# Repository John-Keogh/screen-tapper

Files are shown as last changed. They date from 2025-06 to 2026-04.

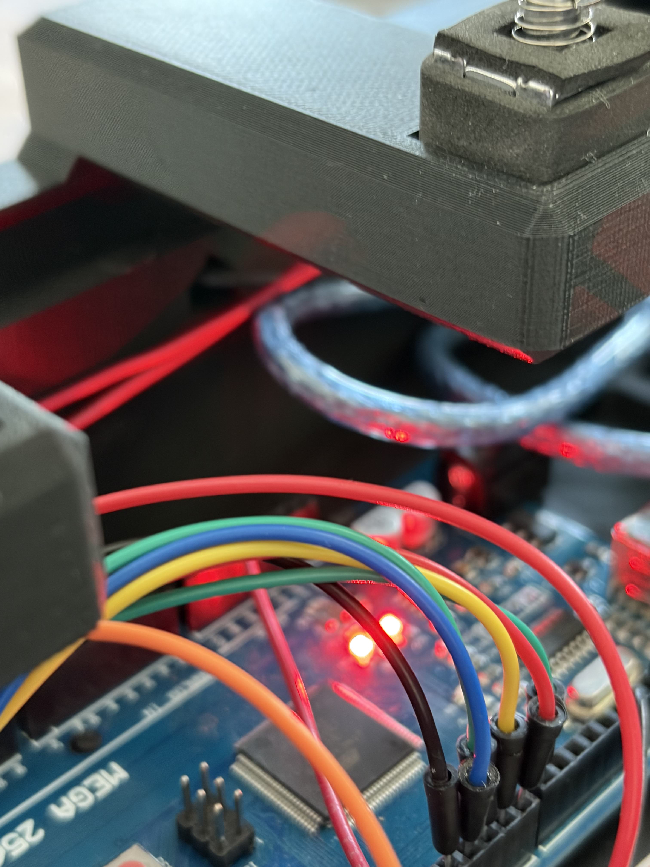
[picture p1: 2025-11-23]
images/1.2/IMG_0665.jpg

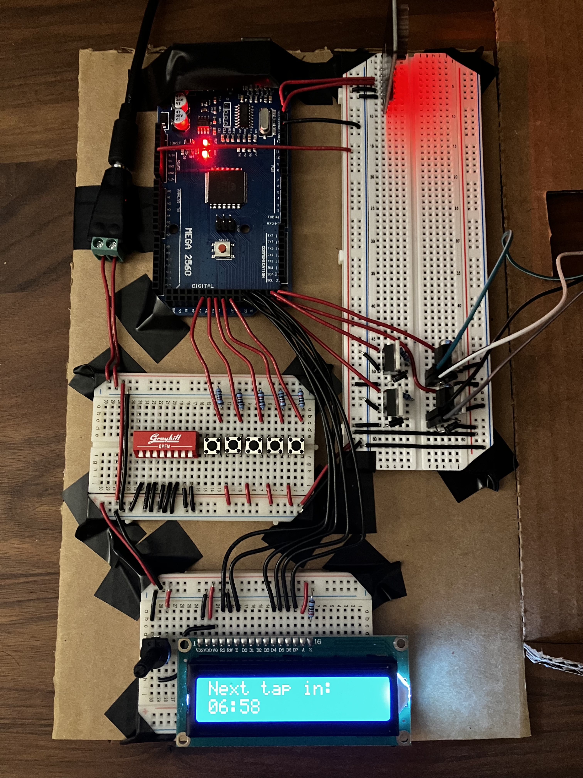
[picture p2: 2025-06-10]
images/beta/IMG_9934.jpeg

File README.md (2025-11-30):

# Screen Tapper

Updated 11/29/25 - current version is 1.2

In 2024, I got addicted to a mobile game containing a currency that can only be acquired by tapping the screen every so often. While I've been running the game 24/7 on an old device, I'm unable to claim this currency because I leave the device at home, and my schedule only allows me to collect for a few hours each day. After getting tired of being bottlenecked by this currency, I decided to try to create a device that would farm for me while I was away. The terms of service of this specific game do explicitly state that the use of external software/hardware to gain an unfair advantage can result in the abuser's account being banned. Arguably, this isn't an unfair advantage because I am not exceeding the limits of what would theoretically be possible if I were to play the game all day every day. Regardless, my goal with this device is to be as undetectable as possible, so I'll omit details about the specific game. I have accepted the fact that I could be banned for this, and I'm okay with that. Learning about electronics and continuing to broaden my engineering skills is well worth the risk, especially since I've been having so much fun with this project.

Overall, this project can be broken up into several main components: the electronic hardware, the software, and the mechanical housing.

## Electronic Hardware

The brains of this device started out on an Arduino Uno R3, but I have since upgraded to an Arduino Mega 2560 for the additional space and I/O support. The power comes from a USB wall adapter through the USB-B port. Interaction with the mobile device is carried out by two 5V solenoid valves that are controlled using one MOSFET each. A Real Time Clock (RTC) module provides time-keeping, and a rotary encoder facilitates user control. An LCD screen provides additional external information. The RTC, MOSFETs, buttons, etc. are all connected using a breadboard.

## Software

The software for the arduino is contained in a single .ino file, but a number of .h/.cpp files organize various functions, such as the LCD display, rotary encoder input, clock. etc. The RTC is used to automatically simulate a "bed time" for the device to better match the behavior of a real person. During normal sleeping hours, the device ceases operations, and at a defined wake-up time, it resumes. Fortunately, the game resource being collected is available on a mostly consistent basis. The average length of time between collections was first determined manually. That length of time (plus some small buffer) acts as the basis for the activation timer for the solenoids. Some additional random noise and occasional delays is then added to simulate the randomness of a human playing the game organically.

## Mechanical housing

The housing has been upgraded using 3d-printed components that securely hold the device and the solenoids. The housing contains internal wire channels for the solenoids to provide a cleaner aesthetic, and the entire thing has been shrunk to be as small as possible with the current overall layout and electronics.

## Future Plans

### Electronic Hardware

While I've upgraded from jumper cables to custom lines of #22 solid core wire (which made a surprisingly big improvement in overall quality of life when working with this thing), I eventually want to learn how to design a single, custom PCB to power the device. As a mechanical engineer who always avoided the electronics lab, I'm expecting this to be the most challenging part of the project. My vision is to have a single board that everything is soldered to and has sufficient customization via on-board controls (buttons/switches) that never needs to be plugged into a computer again after the software is initially installed. One nice-to-have feature I'd like to add eventually is the ability to log all actions onto an SD or micro SD card for future analysis to assess the device's performance. I'd also like to add a third solenoid for even more automated gameplay control.

### Software

Software is mostly complete, offering a variety of manual controls including tap duration, sleep/wake times, bedtime override, and device on/off override. The UI is clean enough, and at this point there are no plans for significant future changes unless I add a third solenoid.

### Mechanical Housing

The current housing is highly simplified, clean, and sturdy. I will need to update it if I add a third solenoid. Otherwise, I would still like to experiment with the idea of creating a travel version, but that would likely only come after I upgraded the electronics to a custom PCB. Otherwise, I may experiment with moving the LCD in order to make the entire device lower profile since that is currently driving the height of the device. That would likely also only come after a custom PCB implementation reduced the wires in the electronics.

TODO:
1) Add third solenoid to rear housing for alternate screen config
2) Extend front housing by ~.5 inches to allow clearance for charging cable
3) Raise tablet surface by ~.25 inches to avoid interference with control knob
4) Improve cover design to ensure clean edges/seam with front housing
5) (Optional) add supports/integration for tablet charging cable

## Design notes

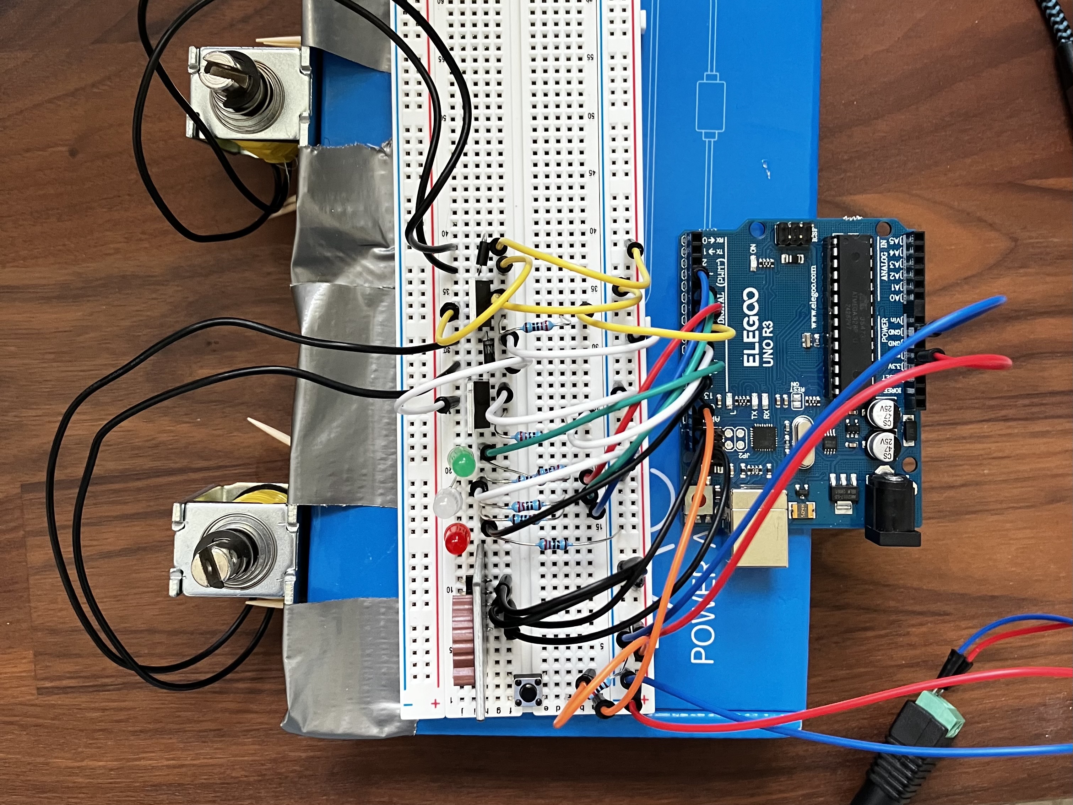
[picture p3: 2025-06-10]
images/alpha/alpha.jpeg

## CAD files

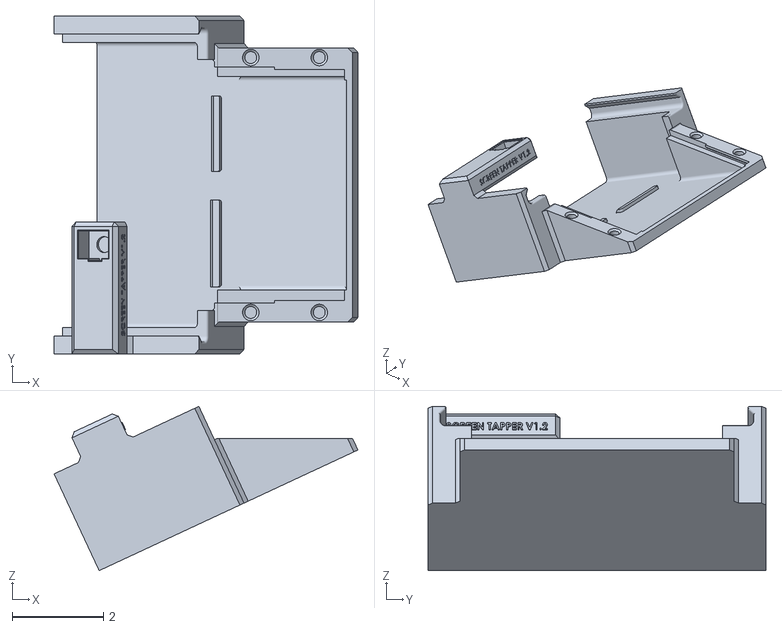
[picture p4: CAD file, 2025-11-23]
hardware/CAD/STL/frontHousing_v3.STL
6.65 x 7.40 x 3.60

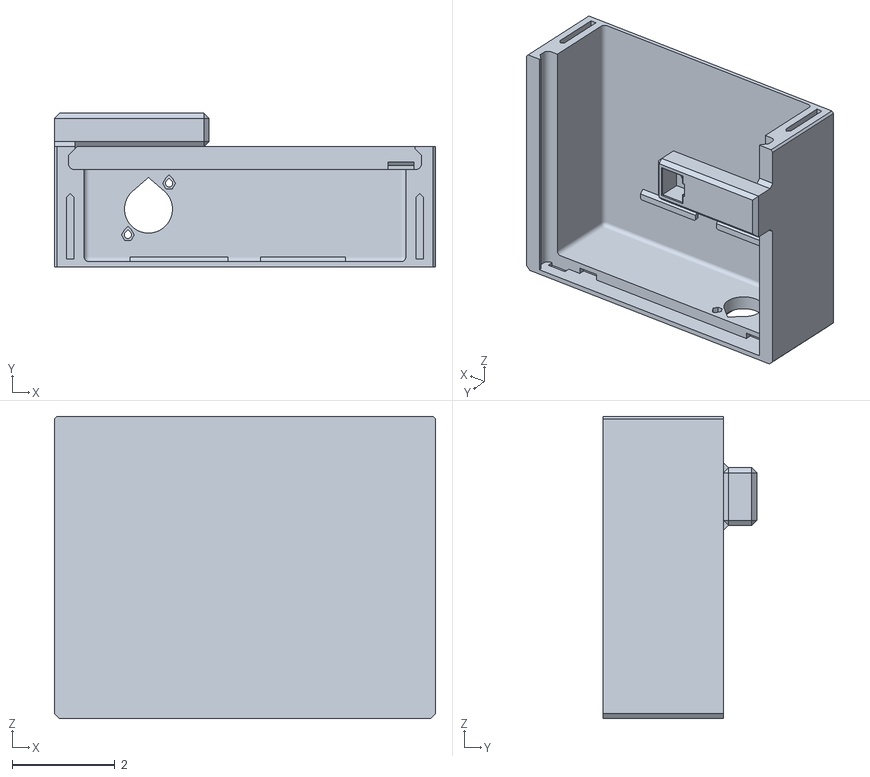
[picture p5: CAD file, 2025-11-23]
hardware/CAD/STL/housing_v4.STL
7.40 x 2.99 x 5.88

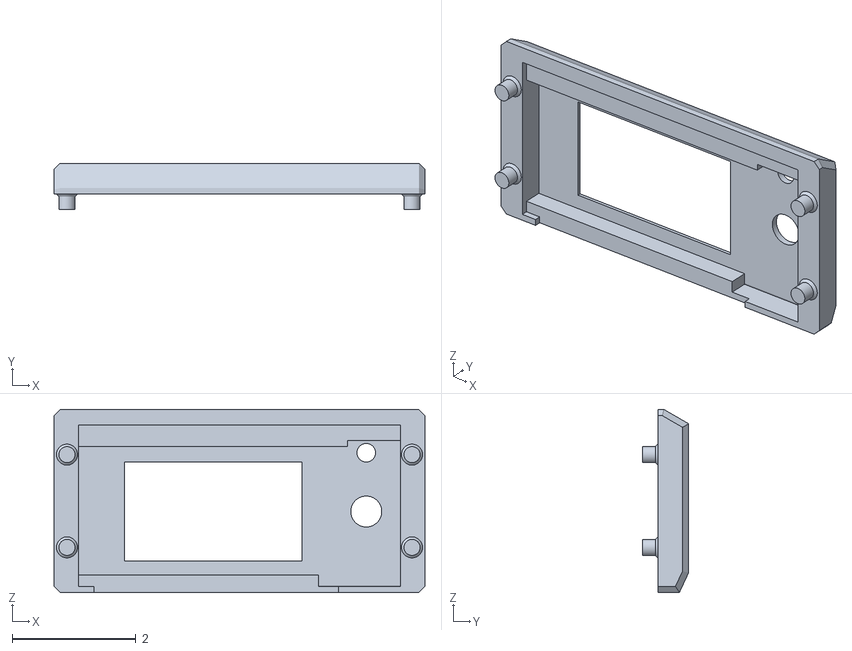
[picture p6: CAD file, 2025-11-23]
hardware/CAD/STL/LcdCover_v5.STL
6.00 x 0.75 x 2.96

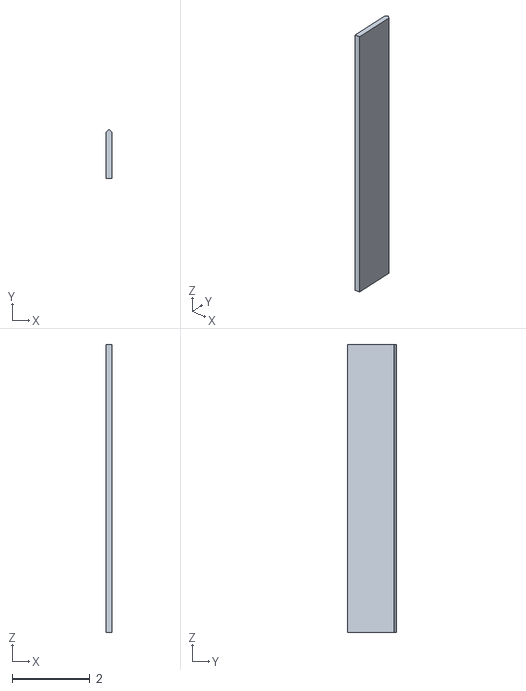
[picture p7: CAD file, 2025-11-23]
hardware/CAD/STL/spline_v2.STL
0.145 x 1.27 x 7.40

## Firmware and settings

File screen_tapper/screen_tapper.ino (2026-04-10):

#include <Wire.h>
#include <RTClib.h>
#include <EEPROM.h>
#include "config.h"
#include "clock.h"
#include "tapper.h"
#include "gem_store.h"
#include "encoder.h"
#include "button.h"
#include "menu.h"
#include "display.h"
#include "settings_store.h"

// ===========================================================================
// Application state
// ===========================================================================

// Tap settings — initialized from EEPROM in setup(), then kept in sync.
uint16_t tapDuration = 160;
uint16_t tapDuty     = 160;

// Active mode parameters (switches between kModeActual and kModeTest)
ModeParams activeMode = kModeActual;

// Sleep schedule — defaults in SleepSchedule struct, overwritten by
// settings_load() if valid EEPROM data exists.
SleepSchedule sched;

// Device flags
bool deviceEnabled   = true;
bool testModeEnabled = false;
bool overrideClock   = false;

// Tap scheduling
unsigned long nextTapTime = 0;

// ===========================================================================
// Helpers
// ===========================================================================

// Build a Settings snapshot from current runtime state for EEPROM saves.
static Settings currentSettings() {
    Settings s;
    s.sched       = sched;
    s.tapDuration = tapDuration;
    s.tapDuty     = tapDuty;
    return s;
}

// ===========================================================================
// Forward declarations
// ===========================================================================

void scheduleNextTap();
static void handleMenuAction(const MenuAction& act);
static MenuView buildMenuView(uint32_t msLeft);

// ===========================================================================
// setup()
// ===========================================================================

void setup() {
    Serial.begin(9600);
    randomSeed(analogRead(0));
    delay(1000);

    clock_begin();

    // Load persisted settings before initializing hardware that uses them.
    Settings s;
    settings_load(s);
    sched       = s.sched;
    tapDuration = s.tapDuration;
    tapDuty     = s.tapDuty;

    tapper_setDuty(tapDuty);
    tapper_begin(AD_GEMS_MOSFET_GATE_PIN, FLOAT_GEMS_MOSFET_GATE_PIN);

    encoder_begin(ENCODER_CLK, ENCODER_DT, ENCODER_SW);
    button_begin(RESET_BUTTON_PIN);
    menu_begin();
    display_begin();

    gem_store_begin();

    Serial.print(F("Lifetime gems: ")); Serial.println(gem_store_read_lifetime());
    Serial.print(F("Sleep:         ")); Serial.print(sched.sleepHour); Serial.print(':'); Serial.println(sched.sleepMinute);
    Serial.print(F("Wake:          ")); Serial.print(sched.wakeHour);  Serial.print(':'); Serial.println(sched.wakeMinute);
    Serial.print(F("Tap duration:  ")); Serial.print(tapDuration); Serial.println(F(" ms"));
    Serial.print(F("Tap duty:      ")); Serial.println(tapDuty);

    scheduleNextTap();
}

// ===========================================================================
// loop()
// ===========================================================================

void loop() {
    uint32_t now = millis();

    // --- Input: encoder ---
    // Processed before rendering so state changes appear in the same frame.
    EncoderEvents ev = encoder_poll();
    bool hadInput = (ev.delta != 0 || ev.pressed);

    MenuAction act;
    bool actionFired = menu_update(ev.delta, ev.pressed, act);
    if (actionFired) {
        handleMenuAction(act);
    }

    // --- Input: reset button ---
    // Reschedules the next tap immediately, regardless of device or sleep state.
    if (button_poll()) {
        scheduleNextTap();
        hadInput = true;
        display_markDirty();
        Serial.println(F("Reset button: next tap rescheduled"));
    }

    // --- Sleep/wake transition ---
    static bool wasAwake = false;
    bool awake = overrideClock || clock_isAwake(sched);
    if (awake && !wasAwake) scheduleNextTap();
    wasAwake = awake;

    // --- Advance tapper state machine ---
    tapper_update(now);

    // --- Fire a tap cycle when it's time ---
    if (!tapper_isActive() && deviceEnabled && awake && (int32_t)(now - nextTapTime) >= 0) {
        tapper_startCycle(
            activeMode.adGemTaps,
            activeMode.floatGemTaps,
            tapDuration,
            activeMode.pauseBetweenTapsMs,
            now
        );

        // Gem accounting: 5 gems per activation, +2 bonus every 6th activation.
        // TODO: refine once earning rates are fully characterized.
        static uint8_t activationCount = 0;
        uint32_t earned = 5;
        activationCount++;
        if (activationCount >= 6) {
            earned += 2;
            activationCount = 0;
        }
        gem_store_add_session(earned);
        scheduleNextTap();
    }

    // --- Compute msLeft ---
    // When the device is off, force to zero so the display shows 00:00.
    uint32_t msLeft = 0;
    if (deviceEnabled) {
        int32_t dt = (int32_t)(nextTapTime - now);
        if (dt > 0) msLeft = (uint32_t)dt;
    }

    // --- Render display ---
    MenuView v = buildMenuView(msLeft);

    if (hadInput || actionFired) {
        display_markDirty();
        display_renderNow(v);
    } else {
        static uint32_t lastSecondsLeft = UINT32_MAX;
        static uint32_t lastGems        = UINT32_MAX;
        uint32_t secondsLeft = msLeft / 1000;
        if (secondsLeft != lastSecondsLeft || v.lifetimeGems != lastGems) {
            display_markDirty();
            lastSecondsLeft = secondsLeft;
            lastGems        = v.lifetimeGems;
        }
        display_render(v);
    }
}

// ===========================================================================
// Tap scheduling
// ===========================================================================

void scheduleNextTap() {
    long jitter = random(-(long)activeMode.jitterRangeMs, (long)activeMode.jitterRangeMs);

    bool addBreak = !testModeEnabled && (random(12) == 0);
    unsigned long base = millis() + activeMode.baseIntervalMs;
    if (addBreak) {
        base += (unsigned long)random(3UL * 60 * 1000, 8UL * 60 * 1000);
    }

    long adjusted = (long)base + jitter;
    if (adjusted < 0) adjusted = 0;
    nextTapTime = (unsigned long)adjusted;
}

// ===========================================================================
// Menu action handler
// ===========================================================================

static void handleMenuAction(const MenuAction& act) {
    switch (act.type) {

        case MenuActionType::GoHome:
            menu_reset();
            display_markDirty();
            break;

        case MenuActionType::ToggleDeviceEnabled:
            deviceEnabled = !deviceEnabled;
            if (!deviceEnabled) {
                tapper_stop();
            } else {
                scheduleNextTap();
            }
            menu_reset();
            display_markDirty();
            break;

        case MenuActionType::ResetNextTap:
            scheduleNextTap();
            menu_reset();
            display_markDirty();
            break;

        case MenuActionType::SetTapDuration:
            if (!act.committed) {
                menu_openTapDurationEditor(tapDuration);
            } else {
                tapDuration = act.u16a;
                settings_save(currentSettings());
                menu_reset();
            }
            display_markDirty();
            break;

        case MenuActionType::SetTapDuty:
            if (!act.committed) {
                menu_openTapDutyEditor(tapDuty);
            } else {
                tapDuty = act.u16a;
                tapper_setDuty(tapDuty);
                settings_save(currentSettings());
                menu_reset();
            }
            display_markDirty();
            break;

        case MenuActionType::EnterSleepTimeEditor:
            menu_openSleepTimeEditor(sched.sleepHour, sched.sleepMinute);
            display_markDirty();
            break;

        case MenuActionType::EnterWakeTimeEditor:
            menu_openWakeTimeEditor(sched.wakeHour, sched.wakeMinute);
            display_markDirty();
            break;

        case MenuActionType::SetSleepTime:
            if (act.committed) {
                sched.sleepHour   = (uint8_t)act.u16a;
                sched.sleepMinute = (uint8_t)act.u16b;
                settings_save(currentSettings());
                menu_reset();
                display_markDirty();
            }
            break;

        case MenuActionType::SetWakeTime:
            if (act.committed) {
                sched.wakeHour   = (uint8_t)act.u16a;
                sched.wakeMinute = (uint8_t)act.u16b;
                settings_save(currentSettings());
                menu_reset();
                display_markDirty();
            }
            break;

        case MenuActionType::SetGemCount:
            if (!act.committed) {
                menu_openGemCountEditor(gem_store_total());
            } else {
                gem_store_write_lifetime(act.u32);
                menu_reset();
            }
            display_markDirty();
            break;

        case MenuActionType::ToggleTestMode:
            testModeEnabled = !testModeEnabled;
            activeMode      = testModeEnabled ? kModeTest : kModeActual;
            scheduleNextTap();
            menu_reset();
            display_markDirty();
            break;

        case MenuActionType::ToggleOverrideSleep:
            overrideClock = !overrideClock;
            menu_reset();
            display_markDirty();
            break;

        default:
            break;
    }
}

// ===========================================================================
// View construction
// ===========================================================================

static MenuView buildMenuView(uint32_t msLeft) {
    MenuHomeData hd;
    hd.lifetimeGems = gem_store_total();
    hd.msLeft       = msLeft;
    menu_setHomeData(hd);

    MenuView v;
    menu_getView(v);

    v.lifetimeGems    = gem_store_total();
    v.msLeft          = msLeft;
    v.sleepHour       = sched.sleepHour;
    v.sleepMinute     = sched.sleepMinute;
    v.wakeHour        = sched.wakeHour;
    v.wakeMinute      = sched.wakeMinute;
    v.deviceEnabled   = deviceEnabled;
    v.overrideClock   = overrideClock;
    v.tapDuration     = tapDuration;
    v.testModeEnabled = testModeEnabled;

    return v;
}

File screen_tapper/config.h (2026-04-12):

#pragma once
#include <stdint.h>

// =============================================================================
// DEBUG
// Comment out this line to strip all debug Serial output from the build.
// =============================================================================
// #define DEBUG

// =============================================================================
// PIN ASSIGNMENTS
// =============================================================================

// MOSFET gates (solenoid drivers)
constexpr int AD_GEMS_MOSFET_GATE_PIN    = 9;
constexpr int FLOAT_GEMS_MOSFET_GATE_PIN = 11;

// Rotary encoder
constexpr int ENCODER_CLK = 40;
constexpr int ENCODER_DT  = 42;
constexpr int ENCODER_SW  = 44;

// 128x64 LCD (ST7920, software SPI) — pins 4, 6, 8 only; backlight not PWM-controlled
constexpr int LCD12864_CLK = 53;
constexpr int LCD12864_DAT = 51;
constexpr int LCD12864_CS  = 49;

// Tap-timer reset button (mounted on LCD module, INPUT_PULLUP, active LOW)
constexpr int RESET_BUTTON_PIN = 31;

// =============================================================================
// TAP TIMING PARAMETERS
// =============================================================================

struct ModeParams {
    uint32_t baseIntervalMs;    // nominal time between tap cycles (ms)
    uint32_t jitterRangeMs;     // +/- random jitter added to each interval (ms)
    uint16_t pauseBetweenTapsMs;// pause between individual taps within a cycle (ms)
    uint8_t  adGemTaps;         // number of taps for the ad-gem solenoid per cycle
    uint8_t  floatGemTaps;      // number of taps for the float-gem solenoid per cycle
};

// Normal operating mode
constexpr ModeParams kModeActual = {
    670000,  // baseIntervalMs
    16000,   // jitterRangeMs
    750,     // pauseBetweenTapsMs
    5,       // adGemTaps
    17,      // floatGemTaps
};

// Faster test mode for verifying hardware behavior
constexpr ModeParams kModeTest = {
    7000,    // baseIntervalMs
    0,       // jitterRangeMs
    750,     // pauseBetweenTapsMs
    3,       // adGemTaps
    5,       // floatGemTaps
};

// =============================================================================
// SLEEP SCHEDULE
// =============================================================================

struct SleepSchedule {
    uint8_t wakeHour   = 7;
    uint8_t wakeMinute = 30;
    uint8_t sleepHour  = 23;
    uint8_t sleepMinute = 59;
};

inline uint16_t toMinutes(uint8_t h, uint8_t m) { return h * 60u + m; }

// =============================================================================
// GEM STORE
// =============================================================================

// Save lifetime gem count to EEPROM after this many session gems accumulate.
constexpr uint16_t kGemSaveThreshold = 25;

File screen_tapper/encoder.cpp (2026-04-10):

#include "encoder.h"
#include "config.h"
#include <Arduino.h>

// Debounce window for the push switch
static constexpr unsigned long SW_DEBOUNCE_MS = 30;

// Pin storage
static uint8_t s_clk = 0xFF;
static uint8_t s_dt  = 0xFF;
static uint8_t s_sw  = 0xFF;

// Rotation detection
static uint8_t s_lastClk = HIGH;

// Switch debounce state (active LOW)
static unsigned long s_swLastChangeMs = 0;
static uint8_t       s_swLastStable   = HIGH;

#ifdef DEBUG
static long s_debugCount = 0;
#endif

void encoder_begin(uint8_t clkPin, uint8_t dtPin, uint8_t swPin) {
    s_clk = clkPin;
    s_dt  = dtPin;
    s_sw  = swPin;

    pinMode(s_clk, INPUT_PULLUP);
    pinMode(s_dt,  INPUT_PULLUP);
    pinMode(s_sw,  INPUT_PULLUP);

    s_lastClk      = digitalRead(s_clk);
    s_swLastStable = digitalRead(s_sw);
    s_swLastChangeMs = millis();

#ifdef DEBUG
    s_debugCount = 0;
    Serial.println(F("[ENC] begin"));
    Serial.print(F("[ENC] pins: CLK=")); Serial.print(s_clk);
    Serial.print(F(" DT="));             Serial.print(s_dt);
    Serial.print(F(" SW="));             Serial.println(s_sw);
    Serial.print(F("[ENC] init CLK="));  Serial.print(s_lastClk);
    Serial.print(F(" DT="));             Serial.println(digitalRead(s_dt));
    Serial.println(F("[ENC] debug counter reset to 0"));
#endif
}

EncoderEvents encoder_poll() {
    EncoderEvents ev;
    unsigned long now = millis();

    // Rotation: report one step per falling edge of CLK
    uint8_t clkNow = digitalRead(s_clk);
    if (clkNow != s_lastClk && clkNow == LOW) {
        uint8_t dtNow = digitalRead(s_dt);
        int8_t step = (dtNow != clkNow) ? +1 : -1;
        // If direction feels reversed on your hardware, flip the sign:
        // step = -step;
        ev.delta += step;

#ifdef DEBUG
        s_debugCount += step;
        Serial.print(F("[ENC] STEP "));
        Serial.print((step > 0) ? F("CW ") : F("CCW "));
        Serial.print(F("clk=")); Serial.print(clkNow);
        Serial.print(F(" dt="));  Serial.print(dtNow);
        Serial.print(F("  count=")); Serial.println(s_debugCount);
#endif
    }
    s_lastClk = clkNow;

    // Press: debounced falling edge detection
    uint8_t swNow = digitalRead(s_sw);
    if (swNow != s_swLastStable && (now - s_swLastChangeMs) >= SW_DEBOUNCE_MS) {
        s_swLastChangeMs = now;
        if (swNow == LOW) {
            ev.pressed = true;
#ifdef DEBUG
            Serial.println(F("[ENC] PRESS"));
#endif
        }
        s_swLastStable = swNow;
    }

    return ev;
}

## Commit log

2025-06-10 Update README.md
    Added initial project description including background, current status, and goals
2025-06-10 Add tap duration controls and resource counter reset button functionality. Rename file.
2025-06-14 Add preliminary EEPROM lifetime tracking and clean up
    - Integrated EEPROM write logic for gem count persistence
    - Added session/lifetime count initialization logic
    - Added readLifetimeGemCount and saveGemCount helper functions
    - Updated LCD display to show lifetime gem count
    - Deleted old screenTapper.ino (moved to new naming convention)
    This sets up the foundation for power-loss-tolerant gem tracking.
    To-Do: Add EEPROM corruption detection and lifetime count factory reset functionality.
    [screen_tapper.ino]
2025-06-14 Fix bug in EEPROM initialization
    [screen_tapper.ino]
2025-06-15 Fix scheduleNextTap function and EEPROM data storage
    - Fixed signed/unsigned interaction between jitter and other variables in scheduleNextTap function
    - Replaced "0" with "0xFF" in clearGemCountEEPROM function to more accurately reset EEPROM gem storage data
    - Added check for 0xFFFFFFFF in readLifetimeGemCount function to properly handle initial condition
    [screen_tapper.ino]
2025-07-02 Refactor solenoid control to support sequential tap sequences; add override clock mode and additional UI improvements
    Major Changes:
    - Replaced blocking `performTaps()` function with non-blocking `startTapSequence()` + `updateTapSequence()` model.
    - Enabled sequential activation of solenoids (adGems followed by floatGems) using a stateful tapping logic.
    - Added `tappingActive` and `adGemsComplete` flags to track tap sequence state.
    - Prevented re-triggering of tap sequences while current sequence is running.
    New Features:
    - Introduced "Override Clock" feature allowing manual bypass of RTC sleep restrictions.
    - Added `OVERRIDE_CLOCK_BUTTON` pin and logic to toggle `overrideClock` flag.
    -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
    [screen_tapper.ino]
2025-07-04 Fix RTC sleep/wake logic to correctly evaluate wake and bed time conditions with override handling.
    [screen_tapper.ino]
2025-07-09 Add one-time tap scheduling when device awakens by detecting sleep-to-awake transition in RTC logic
2025-07-18 Add initial KiCad schematic files
    - First draft for custom PCB integration
    - Includes ATMega2560, ISP, and RTC
    [screen_tapper_pcb.kicad_pcb, screen_tapper_pcb.kicad_sch]
2025-07-18 Reorganize KiCad files
    [screen_tapper_pcb.kicad_pcb]
2025-08-11 Refactor clock and time settings into dedicated modules
    - Moved RTC/clock logic from main .ino into new clock.h/.cpp
    - Added time_settings.h to define SleepSchedule and related constants
    - Updated clock.cpp to use SleepSchedule struct (wake/bed times) for isAwake logic
    - Replaced old deviceAwake handling with clock_isAwake() helper
    - Updated includes and removed redundant clock-related globals from .ino
    [screen_tapper.ino]
2025-08-11 Refactor tapper control into tapper.h/cpp module
    - Moved solenoid tapping logic out of main .ino into new tapper module
2025-08-12 Refactor UI to support timed overlays
    - Implement centralized ui_showOverlay() system with priority, duration, and rate limiting for fhort-term UI messages
    - Fix buffer sizes and formatting for LCD strings
    [screen_tapper.ino, tapper.cpp]
2025-09-02 Add rotary encoder, menu system, and 128x64 LCD UI modules
    - Created encoder.h/cpp for rotary input (rotation + press)
    - Added menu.h/cpp to manage navigation (home, settings, editors)
    - Implemented ui12864_menu.h/cpp renderer using U8g2 for ST7920 LCD
    TODO:
    - Finish ui12864_menu.cpp
    - Integrate encoder/menu/ui12864 with main screen_tapper.ino loop
    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
2025-09-09 Fix tap duration bug and update 128x64 LCD home screen
    - Pushed LCD rendering to after solenoid activation in loop function of screen_tapper.ino
    - Updated viewHome function in ui12864_menu.cpp
    - Added custom symbol in ui12864_menu.cpp
    [screen_tapper.ino]
2025-09-13 Enable 128x64 LCD and rotary encoder module functionality
    - Added handleMenuAction function to screen_tapper.ino
    - Added renderMenuFrame function to screen_tapper.ino
    - Added menu_openTapDurationEditor function to menu .h/.cpp
    - Added menu_openSleepTimeEditor function to menu .h/.cpp
    - Added menu_openWakeTimeEditor function to menu .h/.cpp
    - Updated visuals in numerous functions in ui12864_menu.cpp
2025-10-01 Fix sleep/wake time saving and enable menu interaction during sleep/tap
    [menu.h, screen_tapper.ino]
2025-11-23 Add photos of v1.2
    This is the latest state of the device at the time of uploading
2025-11-23 Enable LCD12864 LED pin and extend MenuView with sleep/wake fields
2025-11-23 Add STEP and STL files
    [LcdCover_v5.STL, frontHousing_v3.STL, housing_v4.STL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]
2025-11-27 Update default parameters for smaller solenoids
2025-11-27 Add PWM power control for solenoids to reduce noise
    [screen_tapper.ino, tapper.cpp]
2025-12-03 Update tapper duration and duty power settings
2025-12-07 Add menu functionality to adjuts tap duty (power) via the LCD
2026-01-04 Redo schematic
    Includes, chip, power, solenoid, LCD, and clock components
    [Screen Tapper v1.0.kicad_sch]
2026-04-10 Refactor: remove legacy 16x2 LCD and button modules, consolidate config, fix bugs
    - Delete ui.cpp/h (16x2 LCD), input.cpp/h (5 legacy buttons)
    - Merge config_pins.h, mode_params.h, time_settings.h into config.h
    - Rename ui12864_menu to display; clean up API naming
    - Move ModeParams to a clean struct with kModeActual/kModeTest instances
    - Move session gem tracking and EEPROM flush logic into gem_store
    - Add #ifdef DEBUG guards to encoder Serial output
    - Fix wrap() modulo bug in menu.cpp (top-of-list scroll now wraps correctly)
    - Remove dead globals, unused rtcAvailable variable, empty maybeMarkDirtyFromView()
    - Fix RTC fail-open: clock_isAwake() now returns true when RTC is unavailable
    - Add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
    [config.h, encoder.cpp]
2026-04-10 feat: EEPROM persistence for tap duration/duty; off-state countdown fix; reset button
    Settings:
    - Consolidate sleep/wake, tap duration, and tap duty into unified Settings
    struct loaded/saved via settings_store module
    - EEPROM layout: sleep/wake at bytes 2-5, tap duration at 6-7, duty at 8
    - All settings use EEPROM.update() to skip writes when value unchanged
    - Settings saved only on confirmed user action, never on startup or editor entry
    New hardware:
    - Add button module (button.h/.cpp): debounced single-button driver
    - Add RESET_BUTTON_PIN = 31 in config.h; press reschedules next tap immediately
    Display/UX:
    - Off-state countdown: msLeft forced to zero when device is disabled
    - Add displ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
    [config.h, screen_tapper.ino]
2026-04-12 Update pin assignments in config.h
